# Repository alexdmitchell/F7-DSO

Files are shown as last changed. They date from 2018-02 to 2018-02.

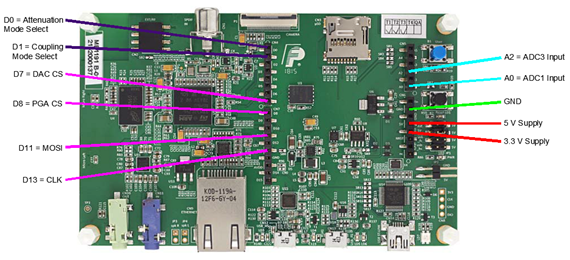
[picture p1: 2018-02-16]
AFE Connections.png

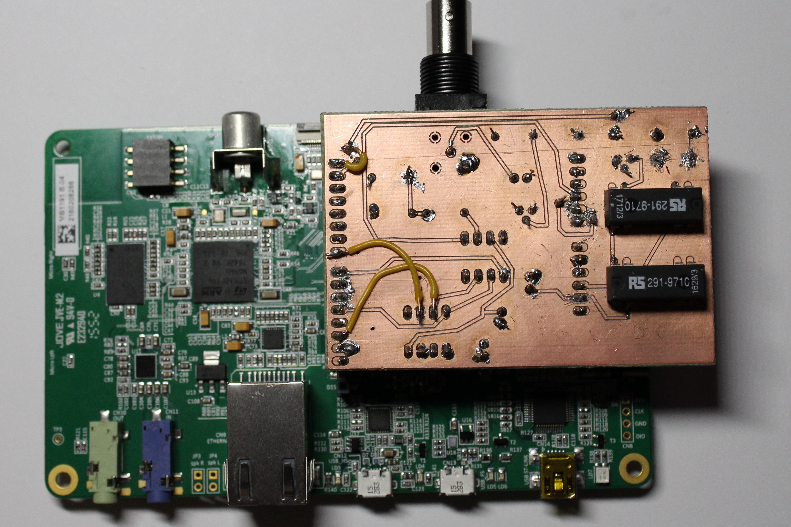
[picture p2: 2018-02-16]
DSO Back.JPG

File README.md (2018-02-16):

# F7-DSO
DSO Project using the STM 32F746G Discovery Board - custom firmware and analogue front end PCB for my MSc project

Project template & initialisation code generated using STMCubeMX

IDE: Keil uVision 5 Professional

Graticule is displayed in a seperate LCD layer, converted from a JPEG image (drawn in AutoCAD) to c header file using the LCD Image Converter tool: http://www.riuson.com/lcd-image-converter

Features:

2.4 MS/s sampling rate achieved using the onboard ADC (ADC3) and DMA

8 bit resolution

Waveform displayed on the integrated LCD

Full touch screen control

Analogue front end PCB including relay switched 1:1/1:10 attenuation & AC/DC Coupling, Programmable Gain Amplifier with DAC for offset
        
Notes:

You will first need to regenerate the project files using CubeMX (to replace the multiple files in STCubeGenerated that were deleted to reduce file count); open STCubeGenerated.ioc and regenerate the project. Then open the project in uVision and recompile - note that the Pro licence is needed as the code is >32kB.

The input for ADC3 is PA2 on the Arduino header on the rear of the board - the full schematic (EAGLE) for the complete analogue front end PCB is included.

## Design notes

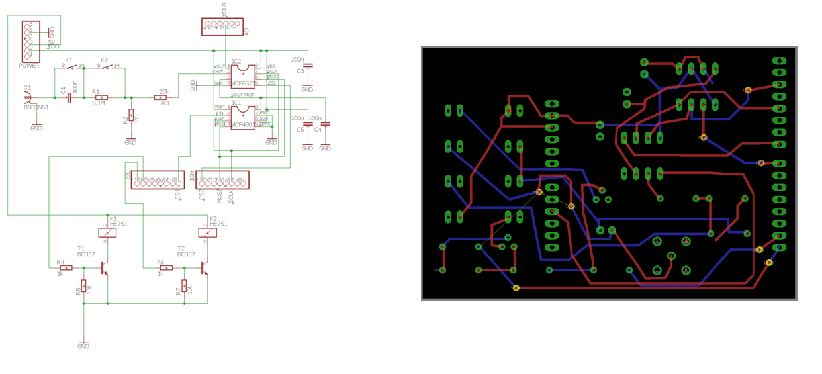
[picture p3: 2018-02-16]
AFE Schematic.png

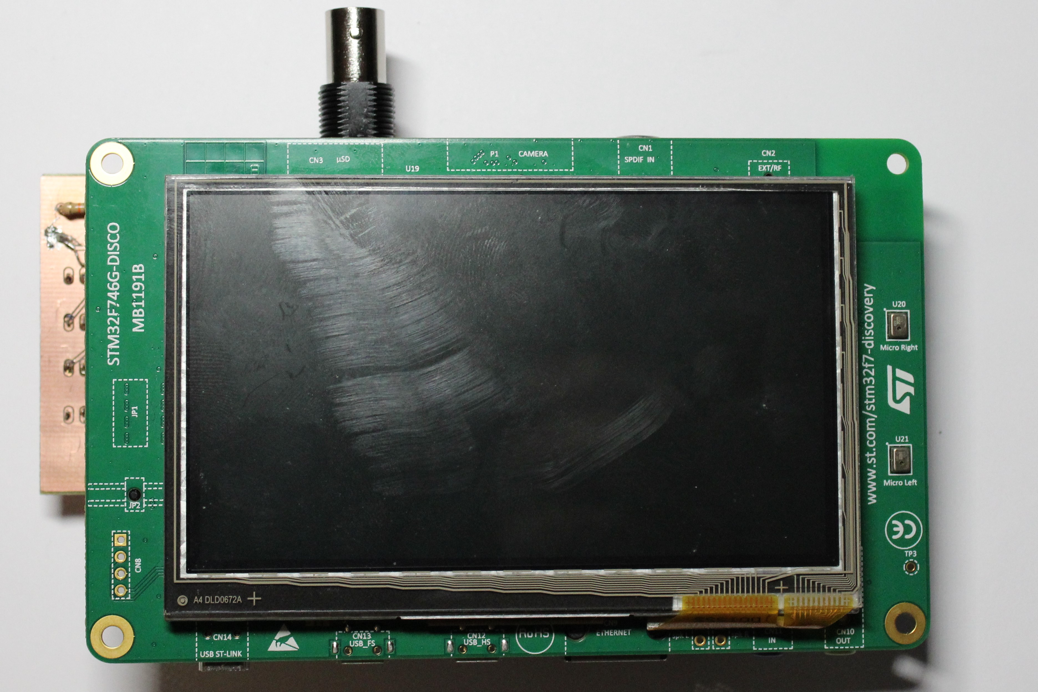
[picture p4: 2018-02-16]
DSO Front.JPG

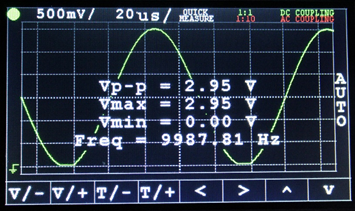
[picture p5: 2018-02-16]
GUI.png

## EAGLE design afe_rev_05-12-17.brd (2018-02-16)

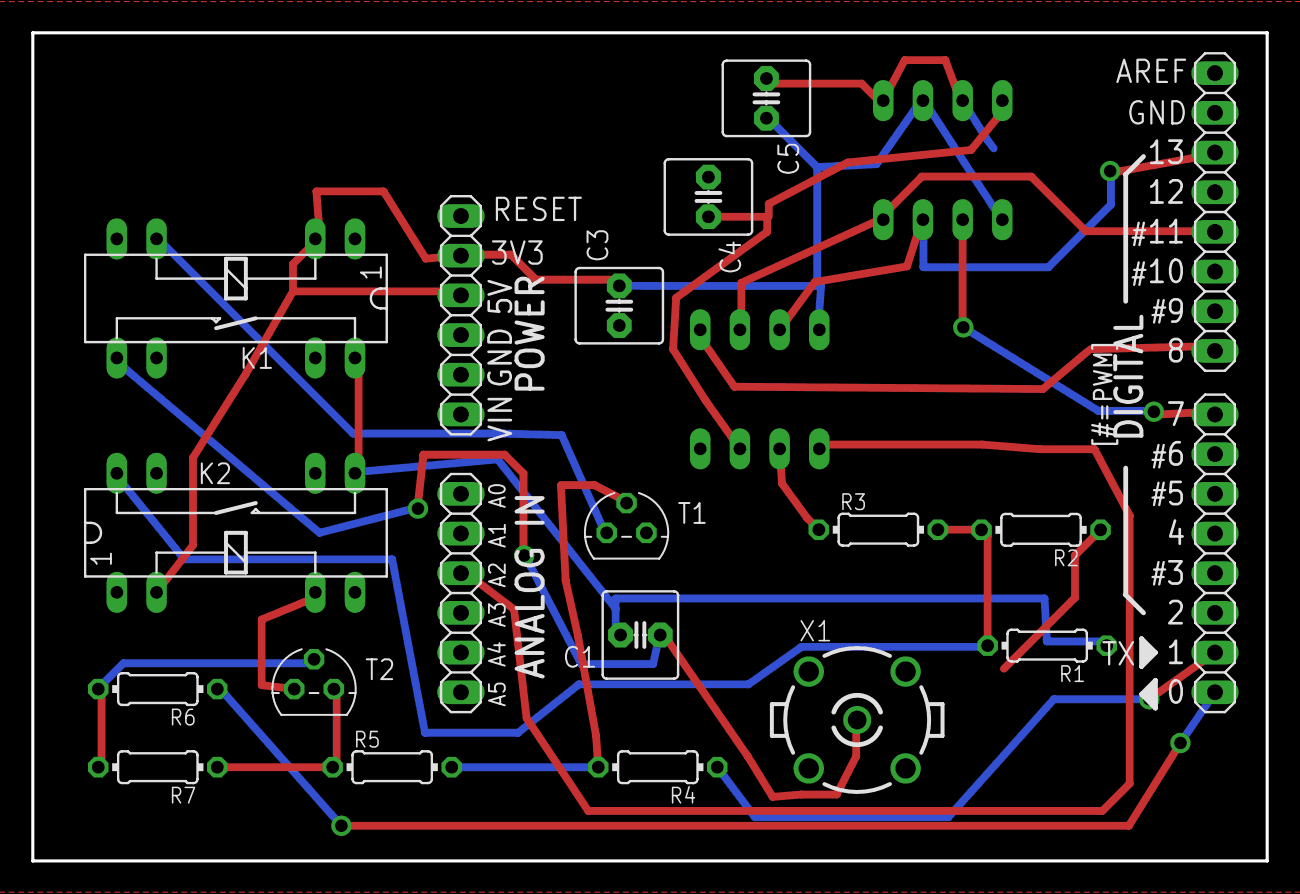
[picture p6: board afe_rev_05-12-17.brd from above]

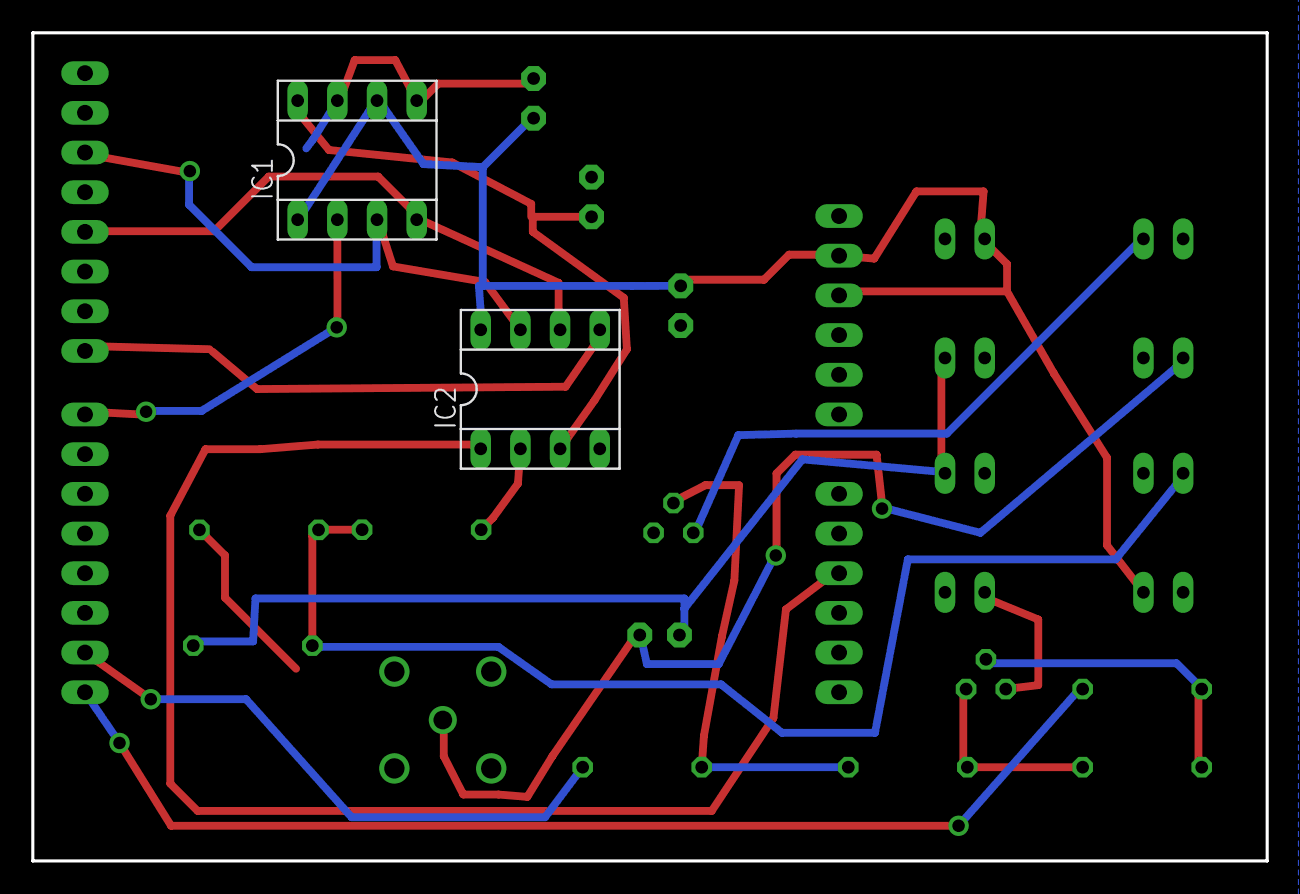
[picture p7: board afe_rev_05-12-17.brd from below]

Board: 2 copper layers, 79.0 x 53.0 mm, 22 parts (2 on the bottom side), 18 nets.

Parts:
AD: 1X06
C1, C3, C4, C5: 100n; C2.5-6
IC1, IC2: SOCKET-08
IOH: 1X08
IOL: 1X08
K1, K2: HE751
POWER: 1X06
R1: 9.1M; 0204/7
R2: 1M; 0204/7
R3: 27k; 0204/7
R4, R6: 1k; 0204/7
R5, R7: 10k; 0204/7
T1, T2: BC337; TO92
X1: BN35N61; B35N61

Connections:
5V: K1.2, K2.2, POWER.3
AC_DC: C1.1, K1.8, X1.1
CH0: IC2.2, R3.1
CS2: IC2.5, IOH.1
GND: C3.1, C4.1, C5.1, IC1.5, IC1.7, IC2.4, POWER.5, R2.1, R5.1, R7.1, T1.1, T2.1, X1.2, X1.3, X1.4, X1.5
MOSI: IC1.4, IC2.6, IOH.4
unnamed: K1.6, T1.3
unnamed: R4.2, R5.2
unnamed: R6.2, R7.2, T2.2
unnamed: K2.6, T2.3
unnamed: IOL.1, R6.1
unnamed: IOL.2, R4.1
unnamed: K2.14, R1.2, R2.2, R3.2
SCLK: IC1.3, IC2.7, IOH.6
VDD: C3.2, C5.2, IC1.1, IC1.6, IC2.8, POWER.2
VOUT: AD.3, IC2.1
VOUT-VREF: C4.2, IC2.3
X1_X10: C1.2, K1.14, K2.8, R1.1

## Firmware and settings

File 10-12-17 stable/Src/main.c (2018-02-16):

/**
  ******************************************************************************
  * File Name          : main.c
  * Description        : Main program body
  ******************************************************************************
  ** This notice applies to any and all portions of this file
  * that are not between comment pairs USER CODE BEGIN and
  * USER CODE END. Other portions of this file, whether 
  * inserted by the user or by software development tools
  * are owned by their respective copyright owners.
  *
  * COPYRIGHT(c) 2018 STMicroelectronics
  *
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
  ******************************************************************************
  */

/* Includes ------------------------------------------------------------------*/
#include "main.h"
#include "stm32f7xx_hal.h"

/* USER CODE BEGIN Includes */
#include "stm32746g_discovery_lcd.h"
#include "stm32746g_discovery_ts.h"
#include "splash.h"
#include "gui.h"
#include "ft5336.h"
#include "RGB565_320x240.h"
#include "spi.h"
#include "stm32f7xx_it.h"
#define ITM_Port8(n) (*((volatile unsigned char *)(0xE0000000+4*n)))
/* USER CODE END Includes */

ADC_HandleTypeDef hadc3;
DMA_HandleTypeDef hdma_adc3;

DMA2D_HandleTypeDef hdma2d;

I2C_HandleTypeDef hi2c3;

LTDC_HandleTypeDef hltdc;

SPI_HandleTypeDef hspi2;

UART_HandleTypeDef huart5;

SDRAM_HandleTypeDef hsdram1;

/* USER CODE BEGIN PV */
extern uint32_t DMA_compl;


uint32_t no_sample_points = 32768;

uint32_t ADC3ConvertedValues[80000]; //array to store ADC values from DMA

uint32_t TSConvertedValues[2048]; //array to store TS values from DMA

uint32_t run_state = 0; //variable used to store start/stop state 0=stopped, 1=running

uint32_t pga_gain[6] = {0,1,2,3,4,5}; //Gain=1,2,4,5,8,10,16,32

float time_div[8] = {0.25,0.5,1,2.5,5,10,25,50}; //stores t/div shift

uint32_t time_div_selected = 2; //stores which t/div mode is currently selected

int32_t v_shift = 0; //stores vertical offset, (20+)221 = centre of trace area

int32_t h_shift = 0; //stores horizontal offset

uint16_t x, y; //variables to store x,y co-ordinates when user presses touchscreen

uint32_t i_min = 20; //stores the start point of data to plot

uint32_t i_max = 462; //stores the end point of data to plot

int32_t trig_level = 100; //stores the trigger level

uint32_t trigset=0;	//stores the trigger state, 1=set, 0=not set

uint16_t pga_gain_selected = 0;	//stores the current point in the gain array selected

uint32_t attenuation = 1; //1= 1:1, 10= 1:10

uint32_t coup_mode = 0; //stores current coupling mode, 0 = dc, 1 = ac


/* USER CODE END PV */

void SystemClock_Config(void);
static void MX_GPIO_Init(void);
static void MX_DMA_Init(void);
static void MX_ADC3_Init(void);
static void MX_DMA2D_Init(void);
static void MX_FMC_Init(void);
static void MX_LTDC_Init(void);
static void MX_UART5_Init(void);
static void MX_I2C3_Init(void);
static void MX_SPI2_Init(void);

/* USER CODE BEGIN PFP */
void startadc3 (void);
void stopadc3 (void);

/* USER CODE END PFP */

int main(void)
{

  /* Enable I-Cache-------------------------------------------------------------*/
  SCB_EnableICache();

  /* Enable D-Cache-------------------------------------------------------------*/
  SCB_EnableDCache();

  /* MCU Configuration----------------------------------------------------------*/

  /* Reset of all peripherals, Initializes the Flash interface and the Systick. */
  HAL_Init();

  /* Configure the system clock */
  SystemClock_Config();

  /* Initialize all configured peripherals */
  MX_GPIO_Init();
  MX_DMA_Init();
  MX_ADC3_Init();
  MX_DMA2D_Init();
  MX_FMC_Init();
  MX_LTDC_Init();
  MX_UART5_Init();
  MX_I2C3_Init();
  MX_SPI2_Init();

  /* USER CODE BEGIN 2 */
	
	/*
	// output to the Debug viewer using the ITM
	ITM_Port8(0) = 'a';
	while (ITM_Port8(0) == 0);
	ITM_Port8(0) = 0x0D;
	while (ITM_Port8(0) == 0);
	ITM_Port8(0) = 0x0A;
	*/
  /* LCD Initialization */
	BSP_LCD_Init();
	BSP_LCD_LayerDefaultInit(0, LCD_FB_START_ADDRESS);

  /* Enable the LCD */
  BSP_LCD_DisplayOn();

 /* Configure Front layer (0) */
  BSP_LCD_SelectLayer(0);
  /* Clear the Background Layer */
  BSP_LCD_Clear(LCD_COLOR_BLACK);
  //BSP_LCD_SetTransparency(1,0xFF);
	BSP_LCD_SetTextColor(LCD_COLOR_WHITE);
	BSP_LCD_SetBackColor(LCD_COLOR_BLACK);
	
	//Initialise Touch Screen
	BSP_TS_Init(480,272);
	printf("LCD initialisation complete\n");
	
	
  printf("Waiting for user to dismiss splash screen\n");
	printf("Ensure that AFE is connected\n");
	
	//Display splash screen on LCD
	drawsplash();

	/* SPI Peripheral Initialisation */
	/* Set the CS high (disable) for DAC & PGA*/
	HAL_GPIO_WritePin(GPIOI, GPIO_PIN_2, GPIO_PIN_SET);
	HAL_GPIO_WritePin(GPIOI, GPIO_PIN_3, GPIO_PIN_SET);

	//Initialise the DAC and PGA
	dac_set_level(0); //zero offset (Vref = 0 V)
	pga_control(0); //zero gain

	/* Initialise the AFE auto-switching as disabled */
	HAL_GPIO_WritePin(GPIOC, GPIO_PIN_6, GPIO_PIN_SET);
	HAL_GPIO_WritePin(GPIOC, GPIO_PIN_7, GPIO_PIN_SET);
	
	printf("DAC & PGA initialised\n");
	
  /* Configure Background Layer (1) */
	/* Comment out the following line to disable the background
	   - reduces programming time during testing */
  BSP_LCD_LayerRgb565Init(1, (uint32_t)&RGB565_320x240); 
	BSP_LCD_SetTransparency(1, 80);
		
	//Initialise touch screen in interrupt mode
	BSP_TS_ITConfig();
	

	cleartrace(); //clear the trace area
	run_state = 1; //Initially start the DSO with trace running
	startadc3(); //start ADC3
	printf("Init completed; DSO started\n");
	
  /* USER CODE END 2 */

  /* Infinite loop */
  /* USER CODE BEGIN WHILE */
  while (1)
  {
  /* USER CODE END WHILE */

  /* USER CODE BEGIN 3 */

		//update the status on LCD
		drawmain();
		drawstatus();
		
		//if current state = 1, start the DSO
		if (run_state == 1)
		{
			drawrun(); //display DSO running
			startadc3(); //start ADC3
		}
		//otherwise pause the DSO
		else
		{
			drawstop(); //display DSO stopped
			stopadc3();	//stop ADC3
		}	
		HAL_Delay(50); //Delay before reloading the ADC + refreshing status
  }

  /* USER CODE END 3 */

}

/** System Clock Configuration
*/
void SystemClock_Config(void)
{

  RCC_OscInitTypeDef RCC_OscInitStruct;
  RCC_ClkInitTypeDef RCC_ClkInitStruct;
  RCC_PeriphCLKInitTypeDef PeriphClkInitStruct;

    /**Configure the main internal regulator output voltage 
    */
  __HAL_RCC_PWR_CLK_ENABLE();

  __HAL_PWR_VOLTAGESCALING_CONFIG(PWR_REGULATOR_VOLTAGE_SCALE1);

    /**Initializes the CPU, AHB and APB busses clocks 
    */
  RCC_OscInitStruct.OscillatorType = RCC_OSCILLATORTYPE_HSE;
  RCC_OscInitStruct.HSEState = RCC_HSE_ON;
  RCC_OscInitStruct.PLL.PLLState = RCC_PLL_ON;
  RCC_OscInitStruct.PLL.PLLSource = RCC_PLLSOURCE_HSE;
  RCC_OscInitStruct.PLL.PLLM = 25;
  RCC_OscInitStruct.PLL.PLLN = 432;
  RCC_OscInitStruct.PLL.PLLP = RCC_PLLP_DIV2;
  RCC_OscInitStruct.PLL.PLLQ = 9;
  if (HAL_RCC_OscConfig(&RCC_OscInitStruct) != HAL_OK)
  {
    _Error_Handler(__FILE__, __LINE__);
  }

    /**Activate the Over-Drive mode 
    */
  if (HAL_PWREx_EnableOverDrive() != HAL_OK)
  {
    _Error_Handler(__FILE__, __LINE__);
  }

    /**Initializes the CPU, AHB and APB busses clocks 
    */
  RCC_ClkInitStruct.ClockType = RCC_CLOCKTYPE_HCLK|RCC_CLOCKTYPE_SYSCLK
                              |RCC_CLOCKTYPE_PCLK1|RCC_CLOCKTYPE_PCLK2;
  RCC_ClkInitStruct.SYSCLKSource = RCC_SYSCLKSOURCE_PLLCLK;
  RCC_ClkInitStruct.AHBCLKDivider = RCC_SYSCLK_DIV1;
  RCC_ClkInitStruct.APB1CLKDivider = RCC_HCLK_DIV4;
  RCC_ClkInitStruct.APB2CLKDivider = RCC_HCLK_DIV2;

  if (HAL_RCC_ClockConfig(&RCC_ClkInitStruct, FLASH_LATENCY_7) != HAL_OK)
  {
    _Error_Handler(__FILE__, __LINE__);
  }

  PeriphClkInitStruct.PeriphClockSelection = RCC_PERIPHCLK_LTDC|RCC_PERIPHCLK_UART5
                              |RCC_PERIPHCLK_I2C3;
  PeriphClkInitStruct.PLLSAI.PLLSAIN = 100;
  PeriphClkInitStruct.PLLSAI.PLLSAIR = 2;
  PeriphClkInitStruct.PLLSAI.PLLSAIQ = 2;
  PeriphClkInitStruct.PLLSAI.PLLSAIP = RCC_PLLSAIP_DIV2;
  PeriphClkInitStruct.PLLSAIDivQ = 1;
  PeriphClkInitStruct.PLLSAIDivR = RCC_PLLSAIDIVR_2;
  PeriphClkInitStruct.Uart5ClockSelection = RCC_UART5CLKSOURCE_PCLK1;
  PeriphClkInitStruct.I2c3ClockSelection = RCC_I2C3CLKSOURCE_PCLK1;
  if (HAL_RCCEx_PeriphCLKConfig(&PeriphClkInitStruct) != HAL_OK)
  {
    _Error_Handler(__FILE__, __LINE__);
  }

    /**Configure the Systick interrupt time 
    */
  HAL_SYSTICK_Config(HAL_RCC_GetHCLKFreq()/8000);

    /**Configure the Systick 
    */
  HAL_SYSTICK_CLKSourceConfig(SYSTICK_CLKSOURCE_HCLK_DIV8);

  /* SysTick_IRQn interrupt configuration */
  HAL_NVIC_SetPriority(SysTick_IRQn, 0, 0);
}

/* ADC3 init function */
static void MX_ADC3_Init(void)
{

  ADC_ChannelConfTypeDef sConfig;

    /**Configure the global features of the ADC (Clock, Resolution, Data Alignment and number of conversion) 
    */
  hadc3.Instance = ADC3;
  hadc3.Init.ClockPrescaler = ADC_CLOCK_SYNC_PCLK_DIV4;
  hadc3.Init.Resolution = ADC_RESOLUTION_8B;
  hadc3.Init.ScanConvMode = ENABLE;
  hadc3.Init.ContinuousConvMode = ENABLE;
  hadc3.Init.DiscontinuousConvMode = DISABLE;
  hadc3.Init.ExternalTrigConvEdge = ADC_EXTERNALTRIGCONVEDGE_NONE;
  hadc3.Init.ExternalTrigConv = ADC_SOFTWARE_START;
  hadc3.Init.DataAlign = ADC_DATAALIGN_RIGHT;
  hadc3.Init.NbrOfConversion = 1;
  hadc3.Init.DMAContinuousRequests = ENABLE;
  hadc3.Init.EOCSelection = ADC_EOC_SINGLE_CONV;
  if (HAL_ADC_Init(&hadc3) != HAL_OK)
  {
    _Error_Handler(__FILE__, __LINE__);
  }

    /**Configure for the selected ADC regular channel its corresponding rank in the sequencer and its sample time. 
    */
  sConfig.Channel = ADC_CHANNEL_7;
  sConfig.Rank = 1;
  sConfig.SamplingTime = ADC_SAMPLETIME_3CYCLES;
  if (HAL_ADC_ConfigChannel(&hadc3, &sConfig) != HAL_OK)
  {
    _Error_Handler(__FILE__, __LINE__);
  }

}

/* DMA2D init function */
static void MX_DMA2D_Init(void)
{

  hdma2d.Instance = DMA2D;
  hdma2d.Init.Mode = DMA2D_M2M;
  hdma2d.Init.ColorMode = DMA2D_OUTPUT_ARGB8888;
  hdma2d.Init.OutputOffset = 0;
  hdma2d.LayerCfg[1].InputOffset = 0;
  hdma2d.LayerCfg[1].InputColorMode = DMA2D_INPUT_ARGB8888;
  hdma2d.LayerCfg[1].AlphaMode = DMA2D_NO_MODIF_ALPHA;
  hdma2d.LayerCfg[1].InputAlpha = 0;
  if (HAL_DMA2D_Init(&hdma2d) != HAL_OK)
  {
    _Error_Handler(__FILE__, __LINE__);
  }

  if (HAL_DMA2D_ConfigLayer(&hdma2d, 1) != HAL_OK)
  {
    _Error_Handler(__FILE__, __LINE__);
  }

}

/* I2C3 init function */
static void MX_I2C3_Init(void)
{

  hi2c3.Instance = I2C3;
  hi2c3.Init.Timing = 0x20404768;
  hi2c3.Init.OwnAddress1 = 0;
  hi2c3.Init.AddressingMode = I2C_ADDRESSINGMODE_7BIT;
  hi2c3.Init.DualAddressMode = I2C_DUALADDRESS_DISABLE;
  hi2c3.Init.OwnAddress2 = 0;
  hi2c3.Init.OwnAddress2Masks = I2C_OA2_NOMASK;
  hi2c3.Init.GeneralCallMode = I2C_GENERALCALL_DISABLE;
  hi2c3.Init.NoStretchMode = I2C_NOSTRETCH_DISABLE;
  if (HAL_I2C_Init(&hi2c3) != HAL_OK)
  {
    _Error_Handler(__FILE__, __LINE__);
  }

    /**Configure Analogue filter 
    */
  if (HAL_I2CEx_ConfigAnalogFilter(&hi2c3, I2C_ANALOGFILTER_ENABLE) != HAL_OK)
  {
    _Error_Handler(__FILE__, __LINE__);
  }

    /**Configure Digital filter 
    */
  if (HAL_I2CEx_ConfigDigitalFilter(&hi2c3, 0) != HAL_OK)
  {
    _Error_Handler(__FILE__, __LINE__);
  }

}

/* LTDC init function */
static void MX_LTDC_Init(void)
{

  LTDC_LayerCfgTypeDef pLayerCfg;

  hltdc.Instance = LTDC;
  hltdc.Init.HSPolarity = LTDC_HSPOLARITY_AL;
  hltdc.Init.VSPolarity = LTDC_VSPOLARITY_AL;
  hltdc.Init.DEPolarity = LTDC_DEPOLARITY_AL;
  hltdc.Init.PCPolarity = LTDC_PCPOLARITY_IPC;
  hltdc.Init.HorizontalSync = 40;
  hltdc.Init.VerticalSync = 9;
  hltdc.Init.AccumulatedHBP = 53;
  hltdc.Init.AccumulatedVBP = 11;
  hltdc.Init.AccumulatedActiveW = 533;
  hltdc.Init.AccumulatedActiveH = 283;
  hltdc.Init.TotalWidth = 565;
  hltdc.Init.TotalHeigh = 285;
  hltdc.Init.Backcolor.Blue = 0;
  hltdc.Init.Backcolor.Green = 0;
  hltdc.Init.Backcolor.Red = 0;
  if (HAL_LTDC_Init(&hltdc) != HAL_OK)
  {
    _Error_Handler(__FILE__, __LINE__);
  }

  pLayerCfg.WindowX0 = 0;
  pLayerCfg.WindowX1 = 480;
  pLayerCfg.WindowY0 = 0;
  pLayerCfg.WindowY1 = 272;
  pLayerCfg.PixelFormat = LTDC_PIXEL_FORMAT_ARGB8888;
  pLayerCfg.Alpha = 255;
  pLayerCfg.Alpha0 = 0;
  pLayerCfg.BlendingFactor1 = LTDC_BLENDING_FACTOR1_CA;
  pLayerCfg.BlendingFactor2 = LTDC_BLENDING_FACTOR2_CA;
  pLayerCfg.FBStartAdress = 0;
  pLayerCfg.ImageWidth = 480;
  pLayerCfg.ImageHeight = 272;
  pLayerCfg.Backcolor.Blue = 0;
  pLayerCfg.Backcolor.Green = 0;
  pLayerCfg.Backcolor.Red = 0;
  if (HAL_LTDC_ConfigLayer(&hltdc, &pLayerCfg, 0) != HAL_OK)
  {
    _Error_Handler(__FILE__, __LINE__);
  }

}

/* SPI2 init function */
static void MX_SPI2_Init(void)
{

  /* SPI2 parameter configuration*/
  hspi2.Instance = SPI2;
  hspi2.Init.Mode = SPI_MODE_MASTER;
  hspi2.Init.Direction = SPI_DIRECTION_2LINES;
  hspi2.Init.DataSize = SPI_DATASIZE_16BIT;
  hspi2.Init.CLKPolarity = SPI_POLARITY_LOW;
  hspi2.Init.CLKPhase = SPI_PHASE_1EDGE;
  hspi2.Init.NSS = SPI_NSS_SOFT;
  hspi2.Init.BaudRatePrescaler = SPI_BAUDRATEPRESCALER_128;
  hspi2.Init.FirstBit = SPI_FIRSTBIT_MSB;
  hspi2.Init.TIMode = SPI_TIMODE_DISABLE;
  hspi2.Init.CRCCalculation = SPI_CRCCALCULATION_DISABLE;
  hspi2.Init.CRCPolynomial = 7;
  hspi2.Init.CRCLength = SPI_CRC_LENGTH_DATASIZE;
  hspi2.Init.NSSPMode = SPI_NSS_PULSE_ENABLE;
  if (HAL_SPI_Init(&hspi2) != HAL_OK)
  {
    _Error_Handler(__FILE__, __LINE__);
  }

}

/* UART5 init function */
static void MX_UART5_Init(void)
{

  huart5.Instance = UART5;
  huart5.Init.BaudRate = 115200;
  huart5.Init.WordLength = UART_WORDLENGTH_7B;
  huart5.Init.StopBits = UART_STOPBITS_1;
  huart5.Init.Parity = UART_PARITY_NONE;
  huart5.Init.Mode = UART_MODE_TX_RX;
  huart5.Init.HwFlowCtl = UART_HWCONTROL_NONE;
  huart5.Init.OverSampling = UART_OVERSAMPLING_16;
  huart5.Init.OneBitSampling = UART_ONE_BIT_SAMPLE_DISABLE;
  huart5.AdvancedInit.AdvFeatureInit = UART_ADVFEATURE_NO_INIT;
  if (HAL_HalfDuplex_Init(&huart5) != HAL_OK)
  {
    _Error_Handler(__FILE__, __LINE__);
  }

}

/** 
  * Enable DMA controller clock
  */
static void MX_DMA_Init(void) 
{
  /* DMA controller clock enable */
  __HAL_RCC_DMA2_CLK_ENABLE();

  /* DMA interrupt init */
  /* DMA2_Stream1_IRQn interrupt configuration */
  HAL_NVIC_SetPriority(DMA2_Stream1_IRQn, 1, 0);
  HAL_NVIC_EnableIRQ(DMA2_Stream1_IRQn);

}
/* FMC initialization function */
static void MX_FMC_Init(void)
{
  FMC_SDRAM_TimingTypeDef SdramTiming;

  /** Perform the SDRAM1 memory initialization sequence
  */
  hsdram1.Instance = FMC_SDRAM_DEVICE;
  /* hsdram1.Init */
  hsdram1.Init.SDBank = FMC_SDRAM_BANK2;
  hsdram1.Init.ColumnBitsNumber = FMC_SDRAM_COLUMN_BITS_NUM_8;
  hsdram1.Init.RowBitsNumber = FMC_SDRAM_ROW_BITS_NUM_12;
  hsdram1.Init.MemoryDataWidth = FMC_SDRAM_MEM_BUS_WIDTH_16;
  hsdram1.Init.InternalBankNumber = FMC_SDRAM_INTERN_BANKS_NUM_4;
  hsdram1.Init.CASLatency = FMC_SDRAM_CAS_LATENCY_1;
  hsdram1.Init.WriteProtection = FMC_SDRAM_WRITE_PROTECTION_DISABLE;
  hsdram1.Init.SDClockPeriod = FMC_SDRAM_CLOCK_DISABLE;
  hsdram1.Init.ReadBurst = FMC_SDRAM_RBURST_DISABLE;
  hsdram1.Init.ReadPipeDelay = FMC_SDRAM_RPIPE_DELAY_0;
  /* SdramTiming */
  SdramTiming.LoadToActiveDelay = 16;
  SdramTiming.ExitSelfRefreshDelay = 16;
  SdramTiming.SelfRefreshTime = 16;
  SdramTiming.RowCycleDelay = 16;
  SdramTiming.WriteRecoveryTime = 16;
  SdramTiming.RPDelay = 16;
  SdramTiming.RCDDelay = 16;

  if (HAL_SDRAM_Init(&hsdram1, &SdramTiming) != HAL_OK)
  {
    _Error_Handler(__FILE__, __LINE__);
  }

}

/** Configure pins as 
        * Analog 
        * Input 
        * Output
        * EVENT_OUT
        * EXTI
*/
static void MX_GPIO_Init(void)
{

  GPIO_InitTypeDef GPIO_InitStruct;

  /* GPIO Ports Clock Enable */
  __HAL_RCC_GPIOE_CLK_ENABLE();
  __HAL_RCC_GPIOB_CLK_ENABLE();
  __HAL_RCC_GPIOC_CLK_ENABLE();
  __HAL_RCC_GPIOA_CLK_ENABLE();
  __HAL_RCC_GPIOG_CLK_ENABLE();
  __HAL_RCC_GPIOJ_CLK_ENABLE();
  __HAL_RCC_GPIOD_CLK_ENABLE();
  __HAL_RCC_GPIOK_CLK_ENABLE();
  __HAL_RCC_GPIOI_CLK_ENABLE();
  __HAL_RCC_GPIOF_CLK_ENABLE();
  __HAL_RCC_GPIOH_CLK_ENABLE();

  /*Configure GPIO pin Output Level */
  HAL_GPIO_WritePin(GPIOB, GPIO_PIN_8|GPIO_PIN_9, GPIO_PIN_RESET);

  /*Configure GPIO pin Output Level */
  HAL_GPIO_WritePin(GPIOI, GPIO_PIN_3|GPIO_PIN_2, GPIO_PIN_RESET);

  /*Configure GPIO pin Output Level */
  HAL_GPIO_WritePin(GPIOK, GPIO_PIN_3, GPIO_PIN_SET);

  /*Configure GPIO pin Output Level */
  HAL_GPIO_WritePin(GPIOI, GPIO_PIN_12, GPIO_PIN_SET);

  /*Configure GPIO pin Output Level */
  HAL_GPIO_WritePin(GPIOC, GPIO_PIN_7|GPIO_PIN_6, GPIO_PIN_RESET);

  /*Configure GPIO pins : PB8 PB9 */
  GPIO_InitStruct.Pin = GPIO_PIN_8|GPIO_PIN_9;
  GPIO_InitStruct.Mode = GPIO_MODE_OUTPUT_PP;
  GPIO_InitStruct.Pull = GPIO_NOPULL;
  GPIO_InitStruct.Speed = GPIO_SPEED_FREQ_LOW;
  HAL_GPIO_Init(GPIOB, &GPIO_InitStruct);

  /*Configure GPIO pin : PB4 */
  GPIO_InitStruct.Pin = GPIO_PIN_4;
  GPIO_InitStruct.Mode = GPIO_MODE_INPUT;
  GPIO_InitStruct.Pull = GPIO_NOPULL;
  HAL_GPIO_Init(GPIOB, &GPIO_InitStruct);

  /*Configure GPIO pins : PI3 PI2 */
  GPIO_InitStruct.Pin = GPIO_PIN_3|GPIO_PIN_2;
  GPIO_InitStruct.Mode = GPIO_MODE_OUTPUT_PP;
  GPIO_InitStruct.Pull = GPIO_NOPULL;
  GPIO_InitStruct.Speed = GPIO_SPEED_FREQ_LOW;
  HAL_GPIO_Init(GPIOI, &GPIO_InitStruct);

  /*Configure GPIO pin : PK3 */
  GPIO_InitStruct.Pin = GPIO_PIN_3;
  GPIO_InitStruct.Mode = GPIO_MODE_OUTPUT_PP;
  GPIO_InitStruct.Pull = GPIO_NOPULL;
  GPIO_InitStruct.Speed = GPIO_SPEED_FREQ_HIGH;
  HAL_GPIO_Init(GPIOK, &GPIO_InitStruct);

  /*Configure GPIO pin : PI12 */
  GPIO_InitStruct.Pin = GPIO_PIN_12;
  GPIO_InitStruct.Mode = GPIO_MODE_OUTPUT_PP;
  GPIO_InitStruct.Pull = GPIO_NOPULL;
  GPIO_InitStruct.Speed = GPIO_SPEED_FREQ_HIGH;
  HAL_GPIO_Init(GPIOI, &GPIO_InitStruct);

  /*Configure GPIO pin : PI0 */
  GPIO_InitStruct.Pin = GPIO_PIN_0;
  GPIO_InitStruct.Mode = GPIO_MODE_INPUT;
  GPIO_InitStruct.Pull = GPIO_NOPULL;
  HAL_GPIO_Init(GPIOI, &GPIO_InitStruct);

  /*Configure GPIO pin : PI11 */
  GPIO_InitStruct.Pin = GPIO_PIN_11;
  GPIO_InitStruct.Mode = GPIO_MODE_IT_RISING;
  GPIO_InitStruct.Pull = GPIO_NOPULL;
  HAL_GPIO_Init(GPIOI, &GPIO_InitStruct);

  /*Configure GPIO pins : PC7 PC6 */
  GPIO_InitStruct.Pin = GPIO_PIN_7|GPIO_PIN_6;
  GPIO_InitStruct.Mode = GPIO_MODE_OUTPUT_PP;
  GPIO_InitStruct.Pull = GPIO_NOPULL;
  GPIO_InitStruct.Speed = GPIO_SPEED_FREQ_LOW;
  HAL_GPIO_Init(GPIOC, &GPIO_InitStruct);

  /*Configure GPIO pins : PG7 PG6 */
  GPIO_InitStruct.Pin = GPIO_PIN_7|GPIO_PIN_6;
  GPIO_InitStruct.Mode = GPIO_MODE_INPUT;
  GPIO_InitStruct.Pull = GPIO_NOPULL;
  HAL_GPIO_Init(GPIOG, &GPIO_InitStruct);

  /*Configure GPIO pin : PH6 */
  GPIO_InitStruct.Pin = GPIO_PIN_6;
  GPIO_InitStruct.Mode = GPIO_MODE_INPUT;
  GPIO_InitStruct.Pull = GPIO_NOPULL;
  HAL_GPIO_Init(GPIOH, &GPIO_InitStruct);

  /* EXTI interrupt init*/
  HAL_NVIC_SetPriority(EXTI15_10_IRQn, 0, 0);
  HAL_NVIC_EnableIRQ(EXTI15_10_IRQn);

}

/* USER CODE BEGIN 4 */

void startadc3 (void)
{
		//Starts ADC3
		if(HAL_ADC_Start(&hadc3) != HAL_OK) 
		{
			//print error if cannot start
			printf("HAL_ADC_Start error!\n");
		}

		//Starts ADC3 DMA request 
		if (HAL_ADC_Start_DMA(&hadc3, (uint32_t*)ADC3ConvertedValues, no_sample_points) != HAL_OK)
		{
			//print error if cannot start
			printf("HAL_ADC_Start_DMA error!\n");
		}
			
}

void stopadc3 (void)
{
		//Stops ADC3 DMA request
		HAL_ADC_Stop_DMA(&hadc3);
}

/* USER CODE END 4 */
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


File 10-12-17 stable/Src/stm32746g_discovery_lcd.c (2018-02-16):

/**
  ******************************************************************************
  * @file    stm32746g_discovery_lcd.c
  * @author  MCD Application Team
  * @version V2.0.0
  * @date    30-December-2016
  * @brief   This file includes the driver for Liquid Crystal Display (LCD) module
  *          mounted on STM32746G-Discovery board.
  @verbatim
  1. How To use this driver:
  --------------------------
     - This driver is used to drive directly an LCD TFT using the LTDC controller.
     - This driver uses timing and setting for RK043FN48H LCD.
  
  2. Driver description:
  ---------------------
    + Initialization steps:
       o Initialize the LCD using the BSP_LCD_Init() function.
       o Apply the Layer configuration using the BSP_LCD_LayerDefaultInit() function.    
       o Select the LCD layer to be used using the BSP_LCD_SelectLayer() function.
       o Enable the LCD display using the BSP_LCD_DisplayOn() function.
  
    + Options
       o Configure and enable the color keying functionality using the 
         BSP_LCD_SetColorKeying() function.
       o Modify in the fly the transparency and/or the frame buffer address
         using the following functions:
         - BSP_LCD_SetTransparency()
         - BSP_LCD_SetLayerAddress() 
    
    + Display on LCD
       o Clear the hole LCD using BSP_LCD_Clear() function or only one specified string
         line using the BSP_LCD_ClearStringLine() function.
       o Display a character on the specified line and column using the BSP_LCD_DisplayChar()
         function or a complete string line using the BSP_LCD_DisplayStringAtLine() function.
       o Display a string line on the specified position (x,y in pixel) and align mode
         using the BSP_LCD_DisplayStringAtLine() function.          
       o Draw and fill a basic shapes (dot, line, rectangle, circle, ellipse, .. bitmap) 
         on LCD using the available set of functions.       
  @endverbatim
  ******************************************************************************
  * @attention
  *
  * <h2><center>&copy; COPYRIGHT(c) 2016 STMicroelectronics</center></h2>
  *
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
  ******************************************************************************
  */ 

/* Includes ------------------------------------------------------------------*/
#include "stm32746g_discovery_lcd.h"
#include "../../../Utilities/Fonts/fonts.h"
#include "../../../Utilities/Fonts/font24.c"
#include "../../../Utilities/Fonts/font20.c"
#include "../../../Utilities/Fonts/font16.c"
#include "../../../Utilities/Fonts/font12.c"
#include "../../../Utilities/Fonts/font8.c"

/** @addtogroup BSP
  * @{
  */

/** @addtogroup STM32746G_DISCOVERY
  * @{
  */
    
/** @addtogroup STM32746G_DISCOVERY_LCD
  * @{
  */ 

/** @defgroup STM32746G_DISCOVERY_LCD_Private_TypesDefinitions STM32746G_DISCOVERY_LCD Private Types Definitions
  * @{
  */ 
/**
  * @}
  */ 

/** @defgroup STM32746G_DISCOVERY_LCD_Private_Defines STM32746G_DISCOVERY LCD Private Defines
  * @{
  */
#define POLY_X(Z)              ((int32_t)((Points + Z)->X))
#define POLY_Y(Z)              ((int32_t)((Points + Z)->Y))      
/**
  * @}
  */ 

/** @defgroup STM32746G_DISCOVERY_LCD_Private_Macros STM32746G_DISCOVERY_LCD Private Macros
  * @{
  */
#define ABS(X)  ((X) > 0 ? (X) : -(X))      
/**
  * @}
  */ 
    
/** @defgroup STM32746G_DISCOVERY_LCD_Private_Variables STM32746G_DISCOVERY_LCD Private Variables
  * @{
  */ 
LTDC_HandleTypeDef  hLtdcHandler;
static DMA2D_HandleTypeDef hDma2dHandler;

/* Default LCD configuration with LCD Layer 1 */
static uint32_t            ActiveLayer = 0;
static LCD_DrawPropTypeDef DrawProp[MAX_LAYER_NUMBER];
/**
  * @}
  */ 

/** @defgroup STM32746G_DISCOVERY_LCD_Private_FunctionPrototypes STM32746G_DISCOVERY_LCD Private Function Prototypes
  * @{
  */ 
static void DrawChar(uint16_t Xpos, uint16_t Ypos, const uint8_t *c);
static void FillTriangle(uint16_t x1, uint16_t x2, uint16_t x3, uint16_t y1, uint16_t y2, uint16_t y3);
static void LL_FillBuffer(uint32_t LayerIndex, void *pDst, uint32_t xSize, uint32_t ySize, uint32_t OffLine, uint32_t ColorIndex);
static void LL_ConvertLineToARGB8888(void * pSrc, void *pDst, uint32_t xSize, uint32_t ColorMode);
/**
  * @}
  */ 

/** @defgroup STM32746G_DISCOVERY_LCD_Exported_Functions STM32746G_DISCOVERY_LCD Exported Functions
  * @{
  */

/**
  * @brief  Initializes the LCD.
  * @retval LCD state
  */
uint8_t BSP_LCD_Init(void)
{    
  /* Select the used LCD */

  /* The RK043FN48H LCD 480x272 is selected */
  /* Timing Configuration */
  hLtdcHandler.Init.HorizontalSync = (RK043FN48H_HSYNC - 1);
  hLtdcHandler.Init.VerticalSync = (RK043FN48H_VSYNC - 1);
  hLtdcHandler.Init.AccumulatedHBP = (RK043FN48H_HSYNC + RK043FN48H_HBP - 1);
  hLtdcHandler.Init.AccumulatedVBP = (RK043FN48H_VSYNC + RK043FN48H_VBP - 1);
  hLtdcHandler.Init.AccumulatedActiveH = (RK043FN48H_HEIGHT + RK043FN48H_VSYNC + RK043FN48H_VBP - 1);
  hLtdcHandler.Init.AccumulatedActiveW = (RK043FN48H_WIDTH + RK043FN48H_HSYNC + RK043FN48H_HBP - 1);
  hLtdcHandler.Init.TotalHeigh = (RK043FN48H_HEIGHT + RK043FN48H_VSYNC + RK043FN48H_VBP + RK043FN48H_VFP - 1);
  hLtdcHandler.Init.TotalWidth = (RK043FN48H_WIDTH + RK043FN48H_HSYNC + RK043FN48H_HBP + RK043FN48H_HFP - 1);
  
  /* LCD clock configuration */
  BSP_LCD_ClockConfig(&hLtdcHandler, NULL);

  /* Initialize the LCD pixel width and pixel height */
  hLtdcHandler.LayerCfg->ImageWidth  = RK043FN48H_WIDTH;
  hLtdcHandler.LayerCfg->ImageHeight = RK043FN48H_HEIGHT;

  /* Background value */
  hLtdcHandler.Init.Backcolor.Blue = 0;
  hLtdcHandler.Init.Backcolor.Green = 0;
  hLtdcHandler.Init.Backcolor.Red = 0;
  
  /* Polarity */
  hLtdcHandler.Init.HSPolarity = LTDC_HSPOLARITY_AL;
  hLtdcHandler.Init.VSPolarity = LTDC_VSPOLARITY_AL; 
  hLtdcHandler.Init.DEPolarity = LTDC_DEPOLARITY_AL;  
  hLtdcHandler.Init.PCPolarity = LTDC_PCPOLARITY_IPC;
  hLtdcHandler.Instance = LTDC;

  if(HAL_LTDC_GetState(&hLtdcHandler) == HAL_LTDC_STATE_RESET)
  {
    /* Initialize the LCD Msp: this __weak function can be rewritten by the application */
    BSP_LCD_MspInit(&hLtdcHandler, NULL);
  }
  HAL_LTDC_Init(&hLtdcHandler);

  /* Assert display enable LCD_DISP pin */
  HAL_GPIO_WritePin(LCD_DISP_GPIO_PORT, LCD_DISP_PIN, GPIO_PIN_SET);

  /* Assert backlight LCD_BL_CTRL pin */
  HAL_GPIO_WritePin(LCD_BL_CTRL_GPIO_PORT, LCD_BL_CTRL_PIN, GPIO_PIN_SET);

#if !defined(DATA_IN_ExtSDRAM)
  /* Initialize the SDRAM */
  BSP_SDRAM_Init();
#endif
    
  /* Initialize the font */
  BSP_LCD_SetFont(&LCD_DEFAULT_FONT);
  
  return LCD_OK;
}
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

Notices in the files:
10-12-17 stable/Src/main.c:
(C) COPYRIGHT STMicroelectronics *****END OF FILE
